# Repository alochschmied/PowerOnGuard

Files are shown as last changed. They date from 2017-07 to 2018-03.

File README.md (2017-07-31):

# PowerOnGuard
Arduino based project limiting the duration a device can consume electricity even if the device consumes only periodically like certain water pumps.

## The outside and general functionality
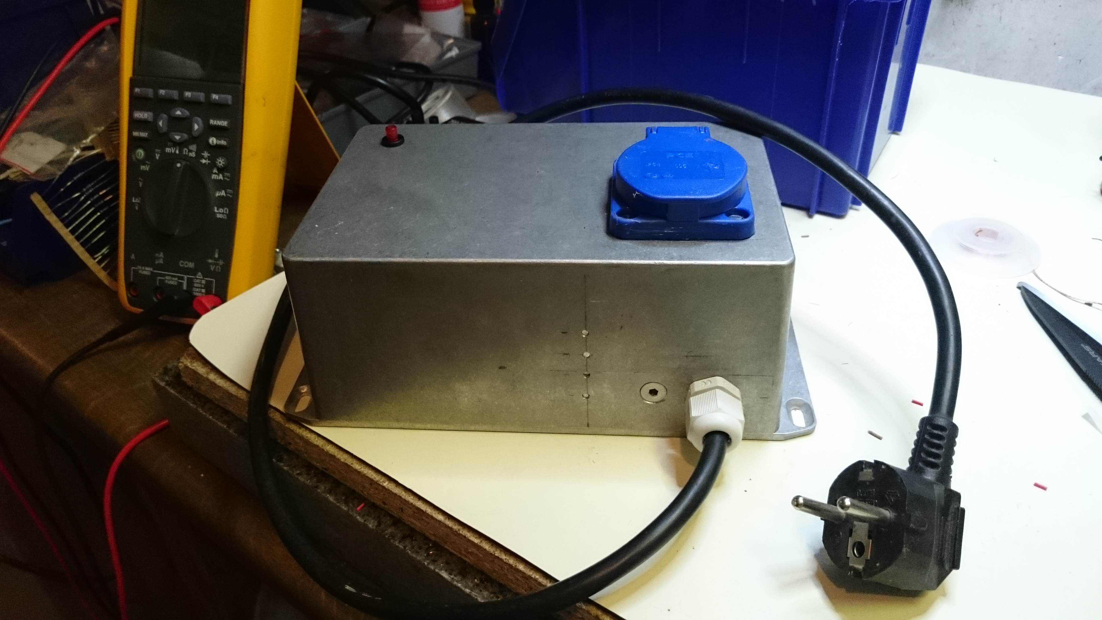
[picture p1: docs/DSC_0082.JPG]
PowerOnGuard0


It is simple: A box that provides electricity while its reset button is not blinking. It starts to blink when power has been consumed for too long. To restart the system and provide power again the reset button must be pressed.

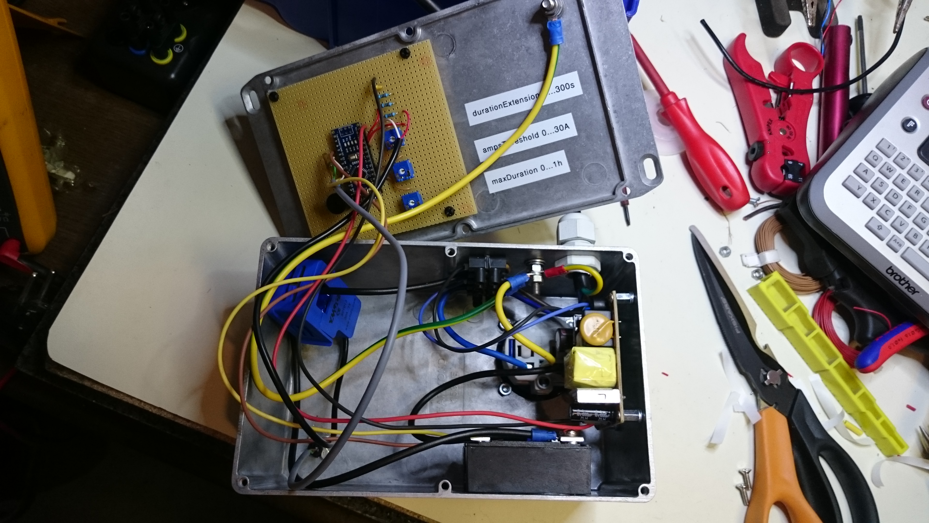
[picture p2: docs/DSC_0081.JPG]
PowerOnGuard1


The components: Switching Power Supply, Microcontroller, Solid State Relay (SSR), Current Sensor, ...

## Main Components

* Aluminum case: 222 x 146 x 55 mm
* 230V power cord and socket
* Switching Power Supply: 
  * Input 230V AC
  * Output 7,5 V DC, 2 A
* Microcontroller: Arduino Nano v3
* SSR: RA2425-D06 (use some thermal compounds for good heat dissipation)
* Current Sensor: SCT 013-030 30A / 1V
* Button with red LED
* Board and all components of the remaining circuit

## Function in more detail
Unlike most commercially available solutions to switch off a device after it consumed energy for too long, this guard works also with devices which have short periods when no power is consumed, but the device is still considered to be consuming power.
Three potentiometers are used to configure the system for a certain device:
* ampsThreshold: 0 ... 10 A

  The minimum amperes that need to drawn such that the algorithm starts to count the time since when this started.
* maxDurationSeconds: 0 ... 3600s (=1h)

  The maximum time in seconds that amps may be drawn. Afterwards the state is toggled and power is switched off.
  The red LED will start to blink. To get power again, the reset switch must be pressed. It will toggle the state.
* durationExtensionSeconds: 0 ... 300s

  Some machines like pumps draw amps for some time and then stop to draw amps, but they are still "on", e.g. pump water.
  This propery is to "virtually" extend the duration where amps are actually drawn to allow the algorithm to account for such machines.

## Circuit
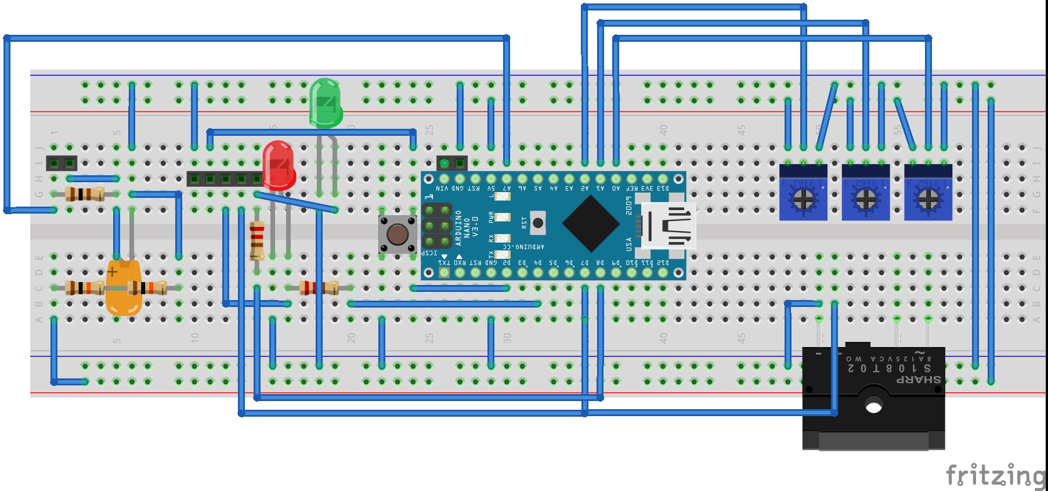
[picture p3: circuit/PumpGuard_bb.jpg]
PowerOnGuard_Circuit_Breadboard

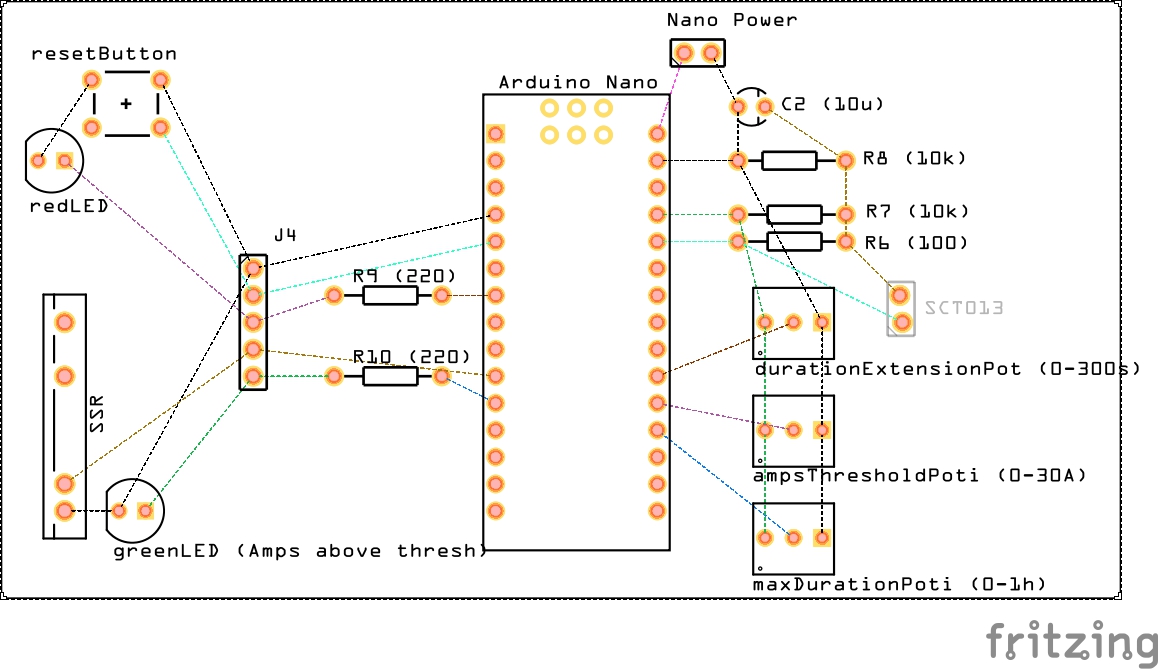
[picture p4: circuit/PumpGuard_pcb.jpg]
PowerOnGuard_Circuit_PCB


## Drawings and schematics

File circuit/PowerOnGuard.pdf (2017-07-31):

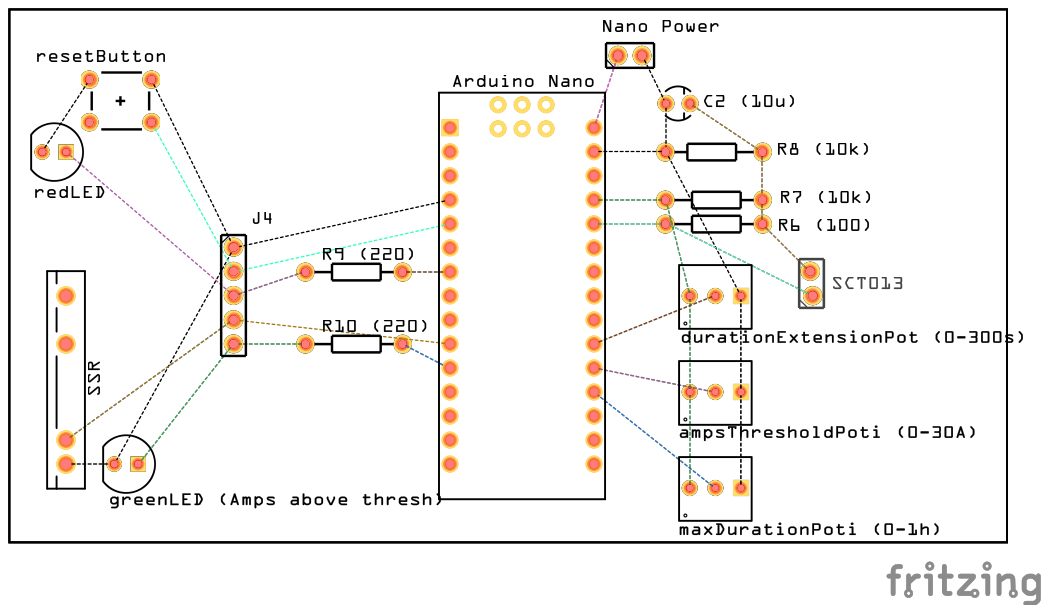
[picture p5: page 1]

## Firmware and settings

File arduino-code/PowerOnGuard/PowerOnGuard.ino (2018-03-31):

#include "Controls.h"

const int meterEveryMillis = 2000;
const int readPotisEveryMillis = 1000;

/**
   Potentiometer setting: 0 ... 300s
   Some machines like pumps draw amps for some time and then stop to draw amps, but they are still "on", e.g. pump water.
   This propery is to "virtually" extend the duration where amps are actually drawn to allow the algorithm to accound
   for such machines.
*/
int durationExtensionSeconds;

/**
   Potentiometer setting: 0 ... 10 A
   The minimum amperes that need to drawn such that the algorithm starts to count the time since when this started.
*/
double ampsThreshold;

/**
   Potentiometer setting: 0 ... 1h
   The maximum time in seconds that amps may be drawn. Afterwards the state is toggled and power is switched off.
   The red LED will start to blink. To get power again, the reset switch must be pressed. It will toggle the state.
*/
int maxDurationSeconds;


/**
   The actual amps drawn currently.
*/
double i_rms;

unsigned long i;

Controls controls = Controls();

EnergyMonitor emon;

enum State {
  RUNNING,
  SHUTDOWN
};

unsigned long lastToggleTime;        // Last state change

volatile enum State state = RUNNING; // We start with power turned on

unsigned long tS;
boolean wasPowerConsumed = false;
unsigned long ampsOnSinceSeconds = 0;
unsigned long virtualPowerConsumptionOnUntilS = 0;

void setup() {
  Serial.begin(9600);

  pinMode(PIN_OUT_SSR, OUTPUT);

  controls.setup(onResetButton);

  double scale = 18.00360 * 4 * (4.06 / 4.55);
  emon.current(7, scale);             // Current: input pin, calibration.

}

void onResetButton() {
  unsigned long now = millis();

  if ((now - lastToggleTime) > 150) {
    lastToggleTime = now;

    if (state == SHUTDOWN) {
      state = RUNNING;
      wasPowerConsumed = false;
      ampsOnSinceSeconds = 0;
      virtualPowerConsumptionOnUntilS = 0;
    } else {
      state = SHUTDOWN;
    }
  }
}



void loop() {
  i++;

  unsigned long tMS = millis();
  tS = tMS / 1000;

  // Somtimes read potis
  if ( (tMS % readPotisEveryMillis) == 0 ) {
    controls.readPotis();

    durationExtensionSeconds = controls.getDurationExtensionSeconds();
    ampsThreshold = controls.getAmpsThreshold();
    maxDurationSeconds = controls.getMaxDurationSeconds();
  }

  // Read current amps
  if ( (tMS % (meterEveryMillis)) == 0 ) {
    i_rms = emon.calcIrms(1480);  // Calculate Irms only
    Serial.println(i_rms);
  }

  if (isPowerConsumed()) {
    controls.powerLedOn(true);

    if (wasPowerConsumed == false) {
      Serial.println("Actual power consumption just started ");
      Serial.println(tS);

      if (virtualPowerConsumptionOnUntilS == 0) {
        ampsOnSinceSeconds = tS;
      }
    } else {
      if (tooLong()) {
        // Power consumed for too long
        state = SHUTDOWN;
      }
    }
  } else {
    controls.powerLedOn(false);
    if (wasPowerConsumed == true) {
      Serial.println("Actual power consumption just stopped ");
      Serial.println(tS);
      // We need assume power consumption for additional durationExtensionSeconds
      virtualPowerConsumptionOnUntilS = tS + durationExtensionSeconds;
    } else {
    }
  }

  if (virtualPowerConsumptionOnUntilS > 0) {
    /*
       Virtual mode has priority. No matter if actual power was off we need to wait until
       time is virtualPowerConsumptionOnUntilS.
       If we waited so long and power is (still) consumed we'll shut down
       power as it was used for too long.

       HOWEVER IF ACTUAL POWER IS CONSUMED WE NEED TO EXTAND AAGAIN
    */
    if (tS > virtualPowerConsumptionOnUntilS) {
      if (isPowerConsumed() && tooLong()) {
        state = SHUTDOWN;
      }
      virtualPowerConsumptionOnUntilS = 0;
    }

    // Just for Power LED:
    if (isPowerConsumed()) {
      controls.powerLedOn(true);
    } else {
      controls.powerLedBlink(true);
    }

  }

  controls.update();

  if (state == SHUTDOWN) {
    controls.signalShutdown(true);
    //Serial.println("SHUTDOWN");
    digitalWrite(PIN_OUT_SSR, LOW);
  } else {
    controls.signalShutdown(false);
    digitalWrite(PIN_OUT_SSR, HIGH);
  }

  if ( (tMS % (meterEveryMillis)) == 0 ) {
    Serial.print(tS);
    Serial.print(", ");
    Serial.print(i_rms);
    Serial.print(", ");
    Serial.print(wasPowerConsumed);
    Serial.print(", ");
    Serial.print(isPowerConsumed());
    Serial.print(", ");
    Serial.print(state);
    Serial.print(", ");
    Serial.print(durationExtensionSeconds);
    Serial.print(", ");
    Serial.print(ampsThreshold);
    Serial.print(", ");
    Serial.print(maxDurationSeconds);
    Serial.print(", ");
    Serial.print(ampsOnSinceSeconds);
    Serial.print(", ");
    Serial.print(virtualPowerConsumptionOnUntilS);

    Serial.print(" (");
    Serial.print("tS,");
    Serial.print("i_rms,");
    Serial.print("wasPowerConsumed,");
    Serial.print("isPowerConsumed,");
    Serial.print("state,");
    Serial.print("durationExtensionSeconds,");
    Serial.print("ampsThreshold,");
    Serial.print("maxDurationSeconds,");
    Serial.print("ampsOnSinceSeconds,");
    Serial.print("virtualPowerConsumptionOnUntilS,");
    Serial.print(")");
    Serial.println("");
  }

  wasPowerConsumed = isPowerConsumed();
}

boolean isPowerConsumed() {
  boolean ret = i_rms > ampsThreshold;
  return ret;
}

boolean tooLong() {
  return (tS - ampsOnSinceSeconds) > maxDurationSeconds;
}

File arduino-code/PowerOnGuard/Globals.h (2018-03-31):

#ifndef Globals_h
#define Globals_h
#include <Arduino.h>
#include <TimerOne.h>
#include <EmonLib.h>



const byte PIN_IN_POTI_AMPS=15;
const byte PIN_IN_POTI_EXT=16;
const byte PIN_IN_POTI_DUR=14;

const byte PIN_OUT_LED_RED = 4;
// const byte PIN_OUT_LED_GREEN = 6;
const byte PIN_OUT_LED_GREEN = 5;
const byte PIN_IN_RESET_BUTTON = 2;
const byte PIN_OUT_SSR = 7;


typedef void (*buttonOnHigh)(void);

#endif

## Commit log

2017-07-31 Added docs and circuit
    [PowerOnGuard.fzz]
2018-03-31 Fixes for main logic
    [Globals.h, PowerOnGuard.ino]
